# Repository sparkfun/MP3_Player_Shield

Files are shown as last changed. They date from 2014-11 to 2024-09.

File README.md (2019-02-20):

SparkFun MP3 Player Shield
==========================

SparkFun MP3 Player Shield  

[*SparkFun MP3 Player Shield (DEV-2660)*](https://www.sparkfun.com/products/12660)

The MP3 Player Shield has a microSD socket, VS1053 decoder IC and all the supporting circuitry to be able to decode and play MP3s from an Arduino.

Repository Contents
-------------------

* **/Documentation** - Data sheets, additional product information
* **/Firmware** - Multiple examples of how to read MP3 files and send them to the VS1053.
* **/Hardware** - All Eagle design files (.brd, .sch)
* **/Production** - Production panel files (.brd)

Documentation
--------------
* **[Hookup Guide](https://learn.sparkfun.com/tutorials/mp3-player-shield-hookup-guide-v15)** - Basic hookup guide for the Mp3 Shield.
* **[SparkFun Fritzing repo](https://github.com/sparkfun/Fritzing_Parts)** - Fritzing diagrams for SparkFun products.
* **[SparkFun 3D Model repo](https://github.com/sparkfun/3D_Models)** - 3D models of SparkFun products. 

Product Versions
----------------
* [DEV-09736](https://www.sparkfun.com/products/retired/9736)- Version 1.0. Retired. 
* [DEV-10628](https://www.sparkfun.com/products/retired/10628)- Version 1.3. Retired. 
* [DEV-12660](https://www.sparkfun.com/products/12660) - Version 1.5. Current. 

Version History
---------------
* [v1.3](https://github.com/sparkfun/MP3_Player_Shield/tree/V_1.3) - Version 1.3 GitHub files. Retired. 
* [v1.5](https://github.com/sparkfun/MP3_Player_Shield/tree/V_1.5) - Version 1.5 GitHub files. Current. 

License Information
-------------------

This product is _**open source**_! 

Please review the LICENSE.md file for license information. 

If you have any questions or concerns on licensing, please contact techsupport@sparkfun.com.

Distributed as-is; no warranty is given.

- Your friends at SparkFun.

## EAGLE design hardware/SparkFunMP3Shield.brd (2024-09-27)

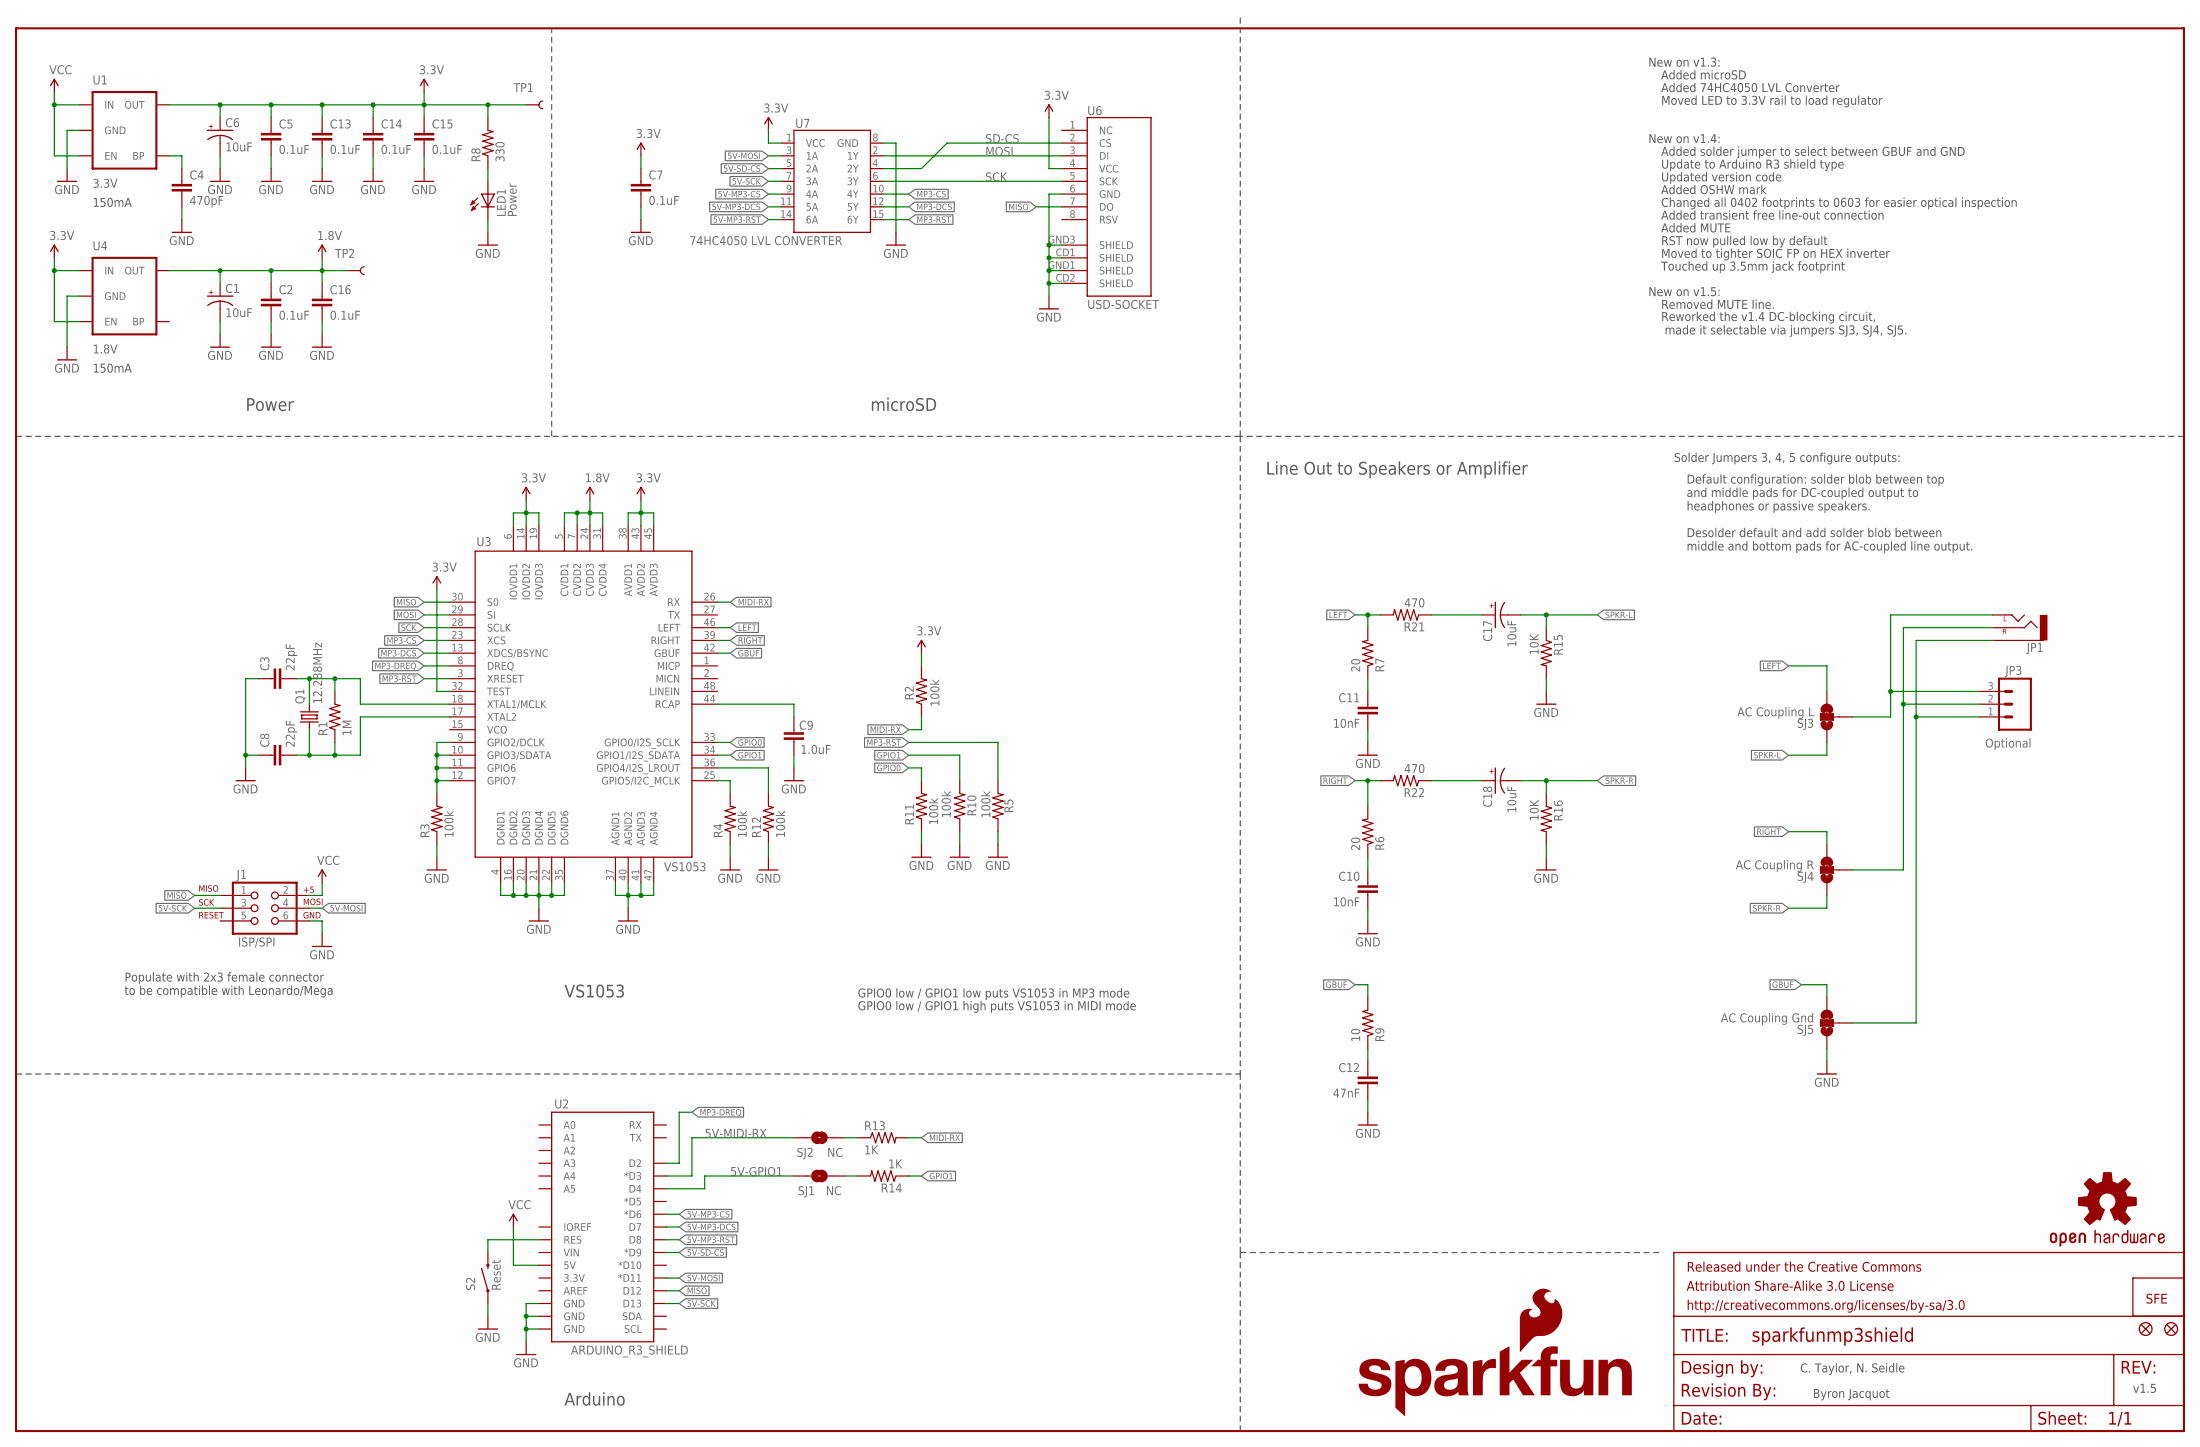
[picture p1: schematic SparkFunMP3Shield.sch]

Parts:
C1, C6, C17, C18: 10uF; EIA3216
C2, C5, C7, C13, C14, C15, C16: 0.1uF; 0603-CAP
C3, C8: 22pF; 0603-CAP
C4: 470pF; 0603-CAP
C9: 1.0uF; 0603-CAP
C10, C11: 10nF; 0603-CAP
C12: 47nF; 0603-CAP
FRAME1: FRAME-LEDGER; CREATIVE_COMMONS
J1: ISP/SPI; 2X3
JP1: AUDIO-JACKSMD2; AUDIO-JACK-3.5MM-SMD
JP3: Optional; 1X03
LED1: Power; LED-0603
LOGO1: OSHW-LOGOS; OSHW-LOGO-S
LOGO2: SFE_LOGO_NAME_FLAME.1_INCH; SFE_LOGO_NAME_FLAME_.1
Q1: 12.288MHz; CRYSTAL-SMD-5X3
R1: 1M; 0603-RES
R2, R3, R4, R5, R10, R11, R12: 100k; 0603-RES
R6, R7: 20; 0603-RES
R8: 330; 0603-RES
R9: 10; 0603-RES
R13, R14: 1K; 0603-RES
R15, R16: 10K; 0603-RES
R21, R22: 470; 0603-RES
S2: Reset; TACTILE_SWITCH_SMD
SJ1, SJ2: NC; SJ_2S-TRACE
SJ3: AC Coupling L; SMT-JUMPER_3_1-NC_TRACE_SILK
SJ4: AC Coupling R; SMT-JUMPER_3_1-NC_TRACE_SILK
SJ5: AC Coupling Gnd; SMT-JUMPER_3_1-NC_TRACE_SILK
TP1, TP2: TEST-POINT3X5; PAD.03X.05
U1: 3.3V; SOT23-5
U2: ARDUINO_R3_SHIELD; UNO_R3_SHIELD
U3: VS1053; LQFP-48
U4: 1.8V; SC70
U6: USD-SOCKET; MICRO-SD-SOCKET-PP
U7: 74HC4050 LVL CONVERTER; SO016
U$1: REVISION
U$4, U$5: FIDUCIAL1X2; FIDUCIAL-1X2
U$8: LOGO-SFENEW; SFE-NEW-WEBLOGO

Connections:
1.8V: C1.A (+), C2.1, C16.1, TP2.P$1, U3.5 (CVDD1), U3.7 (CVDD2), U3.24 (CVDD3), U3.31 (CVDD4), U4.5 (OUT)
3.3V: C5.1, C6.A (+), C7.1, C13.1, C14.1, C15.1, R2.2, R8.2, TP1.P$1, U1.5 (OUT), U3.6 (IOVDD1), U3.14 (IOVDD2), U3.19 (IOVDD3), U3.32 (TEST), U3.38 (AVDD1), U3.43 (AVDD2), U3.45 (AVDD3), U4.1 (IN), U4.3 (EN), U6.4 (VCC), U7.1 (VCC)
5V-GPIO1: SJ1.2, U2.D4
5V-MIDI-RX: SJ2.1, U2.D3 (*D3)
5V-MOSI: J1.4, U2.D11 (*D11), U7.3 (1A)
5V-MP3-CS: U2.D6 (*D6), U7.9 (4A)
5V-MP3-DCS: U2.D7, U7.11 (5A)
5V-MP3-RST: U2.D8, U7.14 (6A)
5V-SCK: J1.3, U2.D13, U7.7 (3A)
5V-SD-CS: U2.D9 (*D9), U7.5 (2A)
ARST: S2.3 (2), U2.RES
G1: R3.2, U3.9 (GPIO2/DCLK), U3.10 (GPIO3/SDATA), U3.11 (GPIO6), U3.12 (GPIO7)
G2: R4.2, U3.25 (GPIO5/I2C_MCLK)
GBUF: R9.2, SJ5.3, U3.42 (GBUF)
GND: C1.C (-), C2.2, C3.1, C4.2, C5.2, C6.C (-), C7.2, C8.1, C9.1, C10.2, C11.2, C12.2, C13.2, C14.2, C15.2, C16.2, J1.6, LED1.C, R3.1, R4.1, R5.1, R10.1, R11.1, R12.1, R15.2, R16.2, S2.1, SJ5.1, U1.2 (GND), U2.GND@0 (GND), U2.GND@1 (GND), U2.GND@2 (GND), U3.4 (DGND1), U3.16 (DGND2), U3.20 (DGND3), U3.21 (DGND4), U3.22 (DGND5), U3.35 (DGND6), U3.37 (AGND1), U3.40 (AGND2), U3.41 (AGND3), U3.47 (AGND4), U4.2 (GND), U6.6 (GND), U6.CD1 (SHIELD), U6.CD2 (SHIELD), U6.GND1 (SHIELD), U6.GND3 (SHIELD), U7.8 (GND)
GPIO0: R11.2, U3.33 (GPIO0/I2S_SCLK)
GPIO1: R10.2, R14.1, U3.34 (GPIO1/I2S_SDATA)
GPIO4: R12.2, U3.36 (GPIO4/I2S_LROUT)
LEFT: R7.2, R21.2, SJ3.3, U3.46 (LEFT)
MIDI-RX: R2.1, R13.2, U3.26 (RX)
MISO: J1.1, U2.D12, U3.30 (S0), U6.7 (DO)
MOSI: U3.29 (SI), U6.3 (DI), U7.2 (1Y)
MP3-CS: U3.23 (XCS), U7.10 (4Y)
MP3-DCS: U3.13 (XDCS/BSYNC), U7.12 (5Y)
MP3-DREQ: U2.D2, U3.8 (DREQ)
MP3-RST: R5.2, U3.3 (XRESET), U7.15 (6Y)
unnamed: C12.1, R9.1
unnamed: C10.1, R6.1
unnamed: R14.2, SJ1.1
unnamed: C11.1, R7.1
unnamed: LED1.A, R8.1
unnamed: R13.1, SJ2.2
unnamed: C3.2, Q1.3 (2), R1.2, U3.18 (XTAL1/MCLK)
unnamed: C8.2, Q1.1, R1.1, U3.17 (XTAL2)
unnamed: JP1.SLEEVE, JP3.1, SJ5.2
unnamed: JP1.RING (RIGHT), JP3.2, SJ4.2
unnamed: JP1.TIP (LEFT), JP3.3, SJ3.2
unnamed: C18.A (+), R22.1
unnamed: C17.A (+), R21.1
unnamed: C4.1, U1.4 (BP)
RCAP: C9.2, U3.44 (RCAP)
RIGHT: R6.2, R22.2, SJ4.3, U3.39 (RIGHT)
SCK: U3.28 (SCLK), U6.5 (SCK), U7.6 (3Y)
SD-CS: U6.2 (CS), U7.4 (2Y)
SPKR-L: C17.C (-), R15.1, SJ3.1
SPKR-R: C18.C (-), R16.1, SJ4.1
VCC: J1.2, U1.1 (IN), U1.3 (EN), U2.5V

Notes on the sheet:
GPIO0 low / GPIO1 high puts VS1053 in MIDI mode
C. Taylor, N. Seidle
New on v1.3:
GPIO0 low / GPIO1 low puts VS1053 in MP3 mode
microSD
Power
Line Out to Speakers or Amplifier
Arduino
VS1053
Moved LED to 3.3V rail to load regulator
Added microSD
Added 74HC4050 LVL Converter
New on v1.4:
Added solder jumper to select between GBUF and GND
Default configuration: solder blob between top and middle pads for DC-coupled output to headphones or passive speakers. Desolder default and add solder blob between middle and bottom pads for AC-coupled line output.
Update to Arduino R3 shield type
Updated version code
Added OSHW mark
Changed all 0402 footprints to 0603 for easier optical inspection
Added transient free line-out connection
Added MUTE
Solder Jumpers 3, 4, 5 configure outputs:
150mA
v1.5
RST now pulled low by default
Populate with 2x3 female connector to be compatible with Leonardo/Mega
Moved to tighter SOIC FP on HEX inverter
Touched up 3.5mm jack footprint
Byron Jacquot
New on v1.5:
Removed MUTE line.
Reworked the v1.4 DC-blocking circuit, made it selectable via jumpers SJ3, SJ4, SJ5.

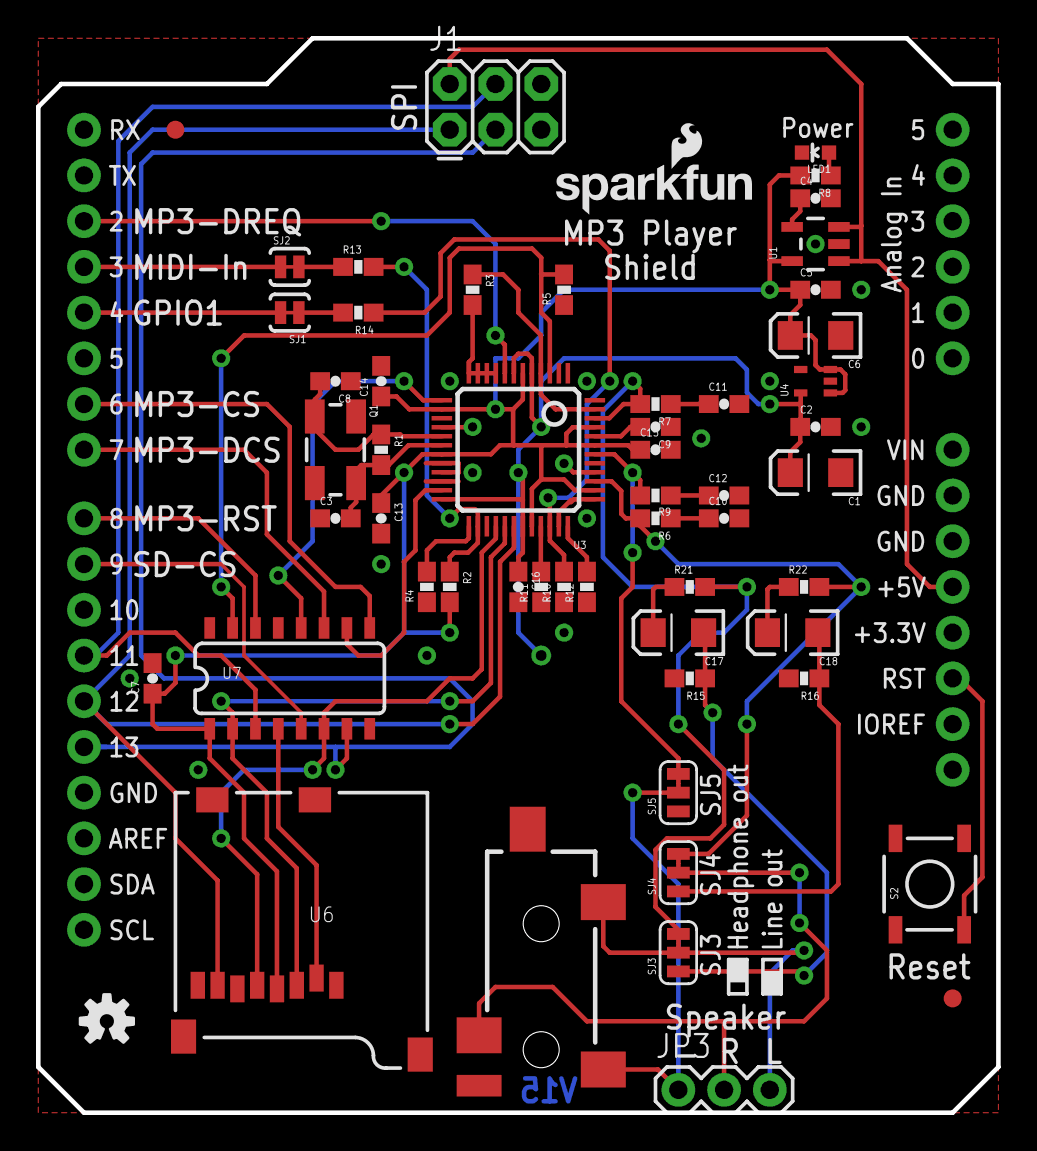
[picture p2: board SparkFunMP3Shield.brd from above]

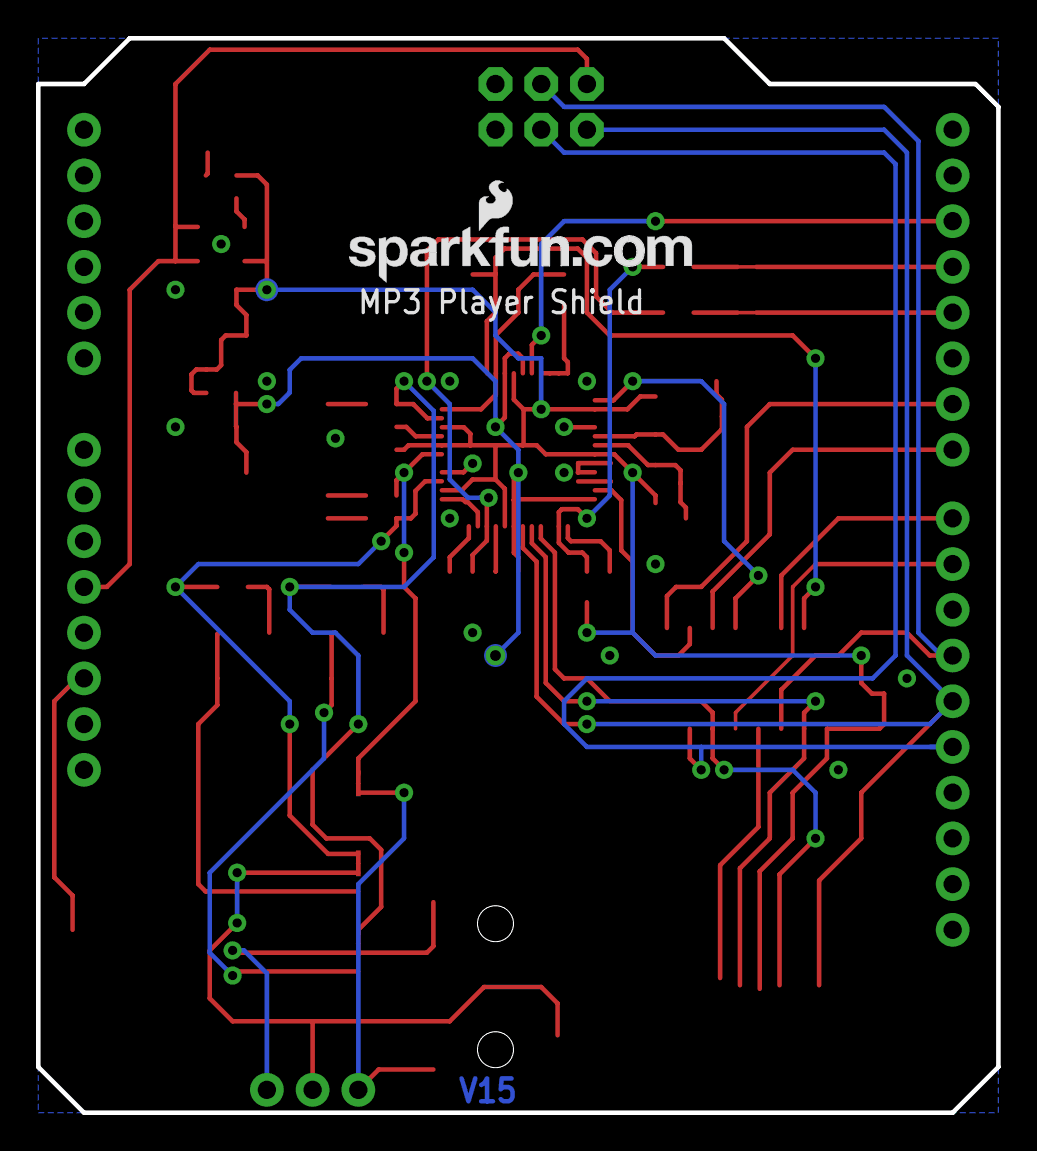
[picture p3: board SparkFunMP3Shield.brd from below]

Board: 2 copper layers, 53.3 x 59.7 mm, 62 parts (3 on the bottom side), 47 nets.

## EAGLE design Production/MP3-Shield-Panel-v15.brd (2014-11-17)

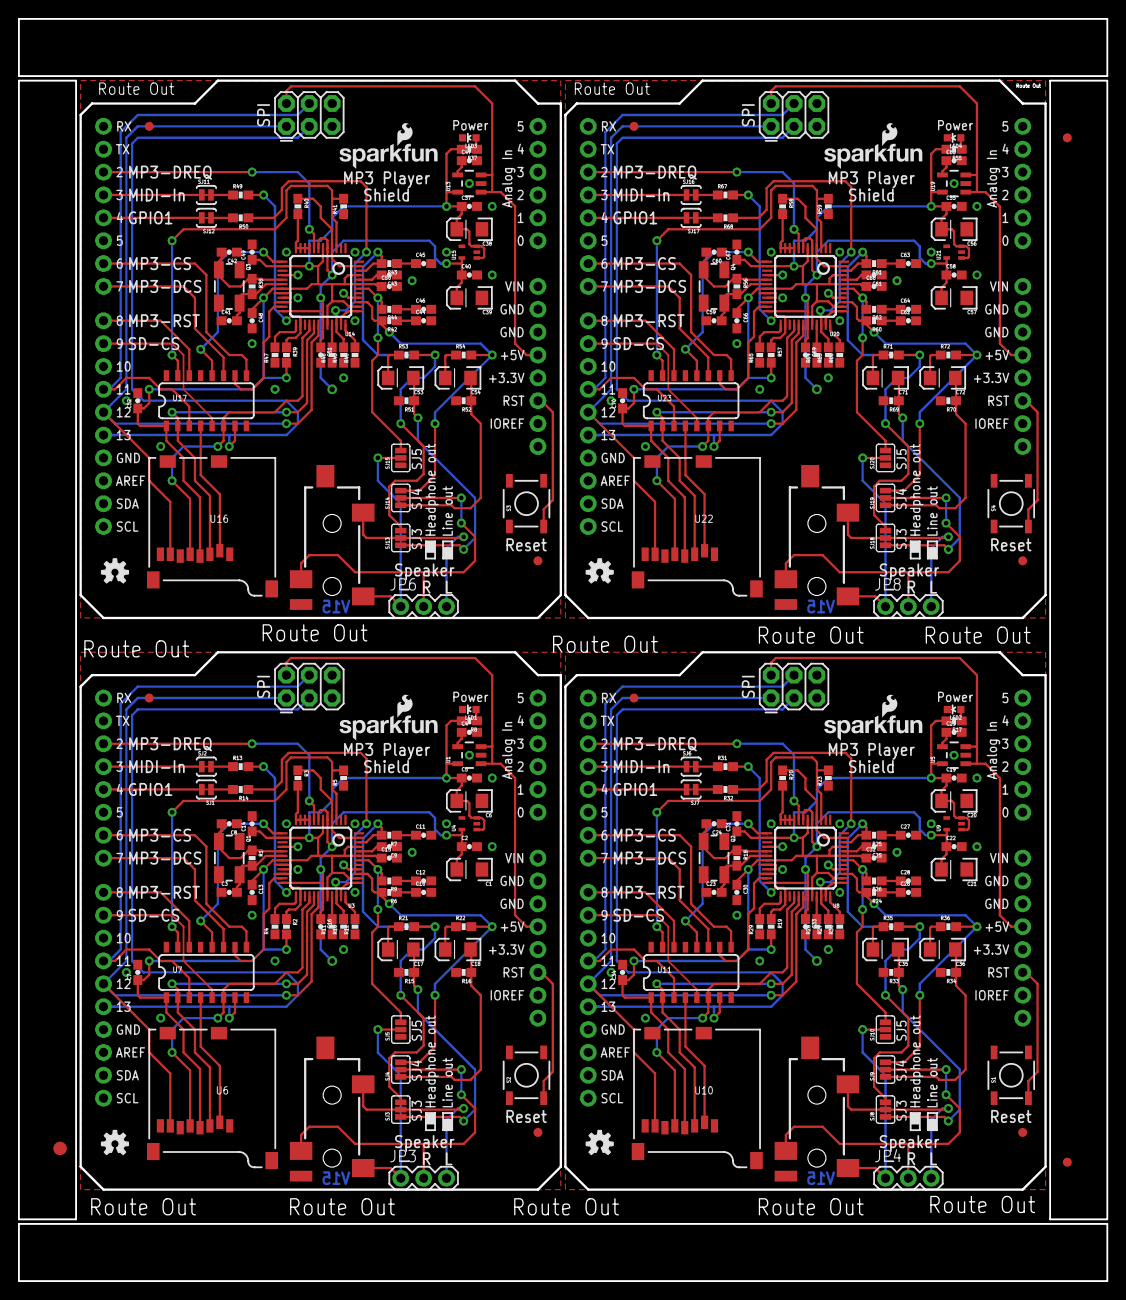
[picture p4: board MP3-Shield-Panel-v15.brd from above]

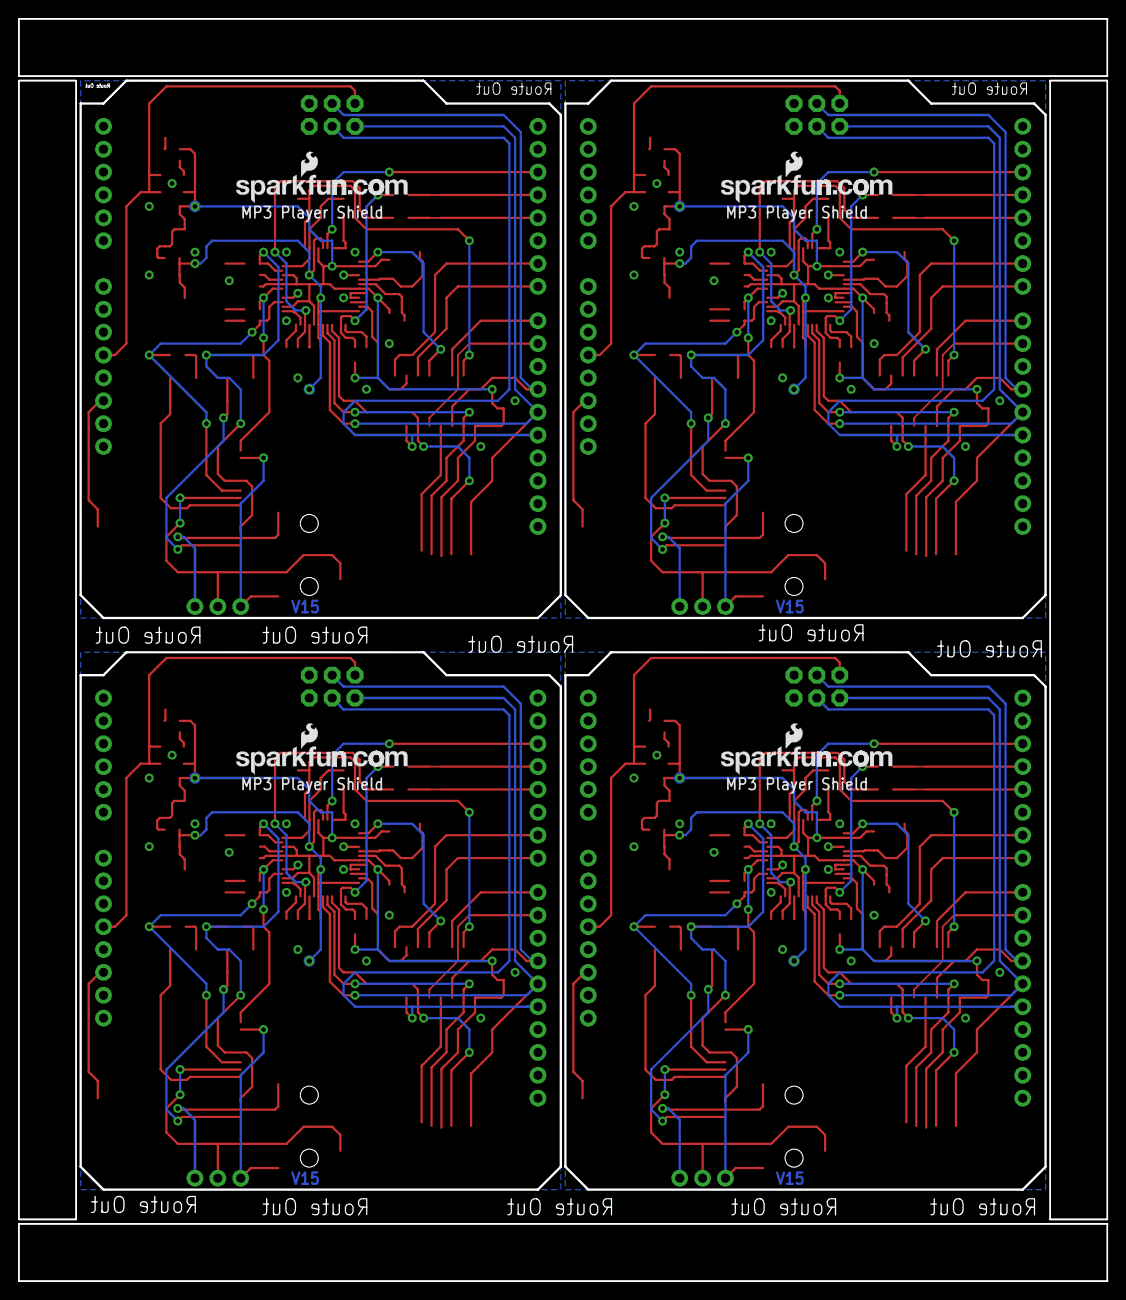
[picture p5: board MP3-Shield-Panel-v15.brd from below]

Board: 2 copper layers, 120.9 x 140.2 mm, 243 parts (12 on the bottom side), 188 nets.

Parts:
C1, C6, C17, C18, C20, C21, C35, C36, C38, C39, C53, C54, C56, C57, C71, C72: 10uF; EIA3216
C2, C5, C7, C13, C14, C15, C16, C19, C22, C30, C31, C32, C33, C34, C37, C40, C48, C49, C50, C51, C52, C55, C58, C66, C67, C68, C69, C70: 0.1uF; 0603-CAP
C3, C8, C23, C24, C41, C42, C59, C60: 22pF; 0603-CAP
C4, C29, C47, C65: 470pF; 0603-CAP
C9, C25, C43, C61: 1.0uF; 0603-CAP
C10, C11, C26, C27, C44, C45, C62, C63: 10nF; 0603-CAP
C12, C28, C46, C64: 47nF; 0603-CAP
E$1: FIDUCIAL-1.5X3
E$4, E$5: FIDUCIAL-1X2
J1, J2, J3, J4: ISP/SPI; 2X3
JP1, JP2, JP5, JP7: AUDIO-JACK-3.5MM-SMD
JP3, JP4, JP6, JP8: Optional; 1X03
LED1, LED2, LED3, LED4: Power; LED-0603
LOGO1, LOGO3, LOGO5, LOGO7: OSHW-LOGOS; OSHW-LOGO-S
LOGO2, LOGO4, LOGO6, LOGO8: SFE_LOGO_NAME_FLAME.1_INCH; SFE_LOGO_NAME_FLAME_.1
Q1, Q2, Q3, Q4: 12.288MHz; CRYSTAL-SMD-5X3
R1, R18, R38, R56: 1M; 0603-RES
R2, R3, R4, R5, R10, R11, R12, R19, R20, R23, R27, R28, R29, R30, R39, R40, R41, R45, R46, R47, R48, R57, R58, R59, R63, R64, R65, R66: 100k; 0603-RES
R6, R7, R24, R25, R42, R43, R60, R61: 20; 0603-RES
R8, R17, R37, R55: 330; 0603-RES
R9, R26, R44, R62: 10; 0603-RES
R13, R14, R31, R32, R49, R50, R67, R68: 1K; 0603-RES
R15, R16, R33, R34, R51, R52, R69, R70: 10K; 0603-RES
R21, R22, R35, R36, R53, R54, R71, R72: 470; 0603-RES
S1, S2, S3, S4: Reset; TACTILE_SWITCH_SMD
SJ1, SJ2, SJ6, SJ7, SJ11, SJ12, SJ16, SJ17: NC; SJ_2S-TRACE
SJ3, SJ8, SJ13, SJ18: AC Coupling L; PAD-JUMPER-3-2OF3_NC_BY_PASTE_YES_SILK_FULL_BOX
SJ4, SJ9, SJ14, SJ19: AC Coupling R; PAD-JUMPER-3-2OF3_NC_BY_PASTE_YES_SILK_FULL_BOX
SJ5, SJ10, SJ15, SJ20: AC Coupling Gnd; PAD-JUMPER-3-2OF3_NC_BY_PASTE_YES_SILK_FULL_BOX
TP1, TP2, TP3, TP4, TP5, TP6, TP7, TP8: PAD.03X.05
U1, U5, U13, U19: 3.3V; SOT23-5
U2, U12, U18, U24: ARDUINO_R3_SHIELD; UNO_R3_SHIELD
U3, U8, U14, U20: VS1053; LQFP-48
U4, U9, U15, U21: 1.8V; SC70
U6, U10, U16, U22: USD-SOCKET; MICRO-SD-SOCKET-PP
U7, U11, U17, U23: 74HC4050 LVL CONVERTER; SO016
U$1, U$2, U$4, U$5, U$6, U$7, U$10, U$11: FIDUCIAL1X2; FIDUCIAL-1X2
U$3, U$8, U$9, U$12: LOGO-SFENEW; SFE-NEW-WEBLOGO

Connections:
1.8V: C1.A, C2.1, C16.1, TP2.P$1, U3.5, U3.7, U3.24, U3.31, U4.5
1.8V1: C21.A, C22.1, C33.1, TP4.P$1, U8.5, U8.7, U8.24, U8.31, U9.5
1.8V2: C39.A, C40.1, C51.1, TP6.P$1, U14.5, U14.7, U14.24, U14.31, U15.5
1.8V3: C57.A, C58.1, C69.1, TP8.P$1, U20.5, U20.7, U20.24, U20.31, U21.5
3.3V: C5.1, C6.A, C7.1, C13.1, C14.1, C15.1, R2.2, R8.2, TP1.P$1, U1.5, U3.6, U3.14, U3.19, U3.32, U3.38, U3.43, U3.45, U4.1, U4.3, U6.4, U7.1
3.3V1: C19.1, C20.A, C30.1, C31.1, C32.1, C34.1, R17.2, R19.2, TP3.P$1, U5.5, U8.6, U8.14, U8.19, U8.32, U8.38, U8.43, U8.45, U9.1, U9.3, U10.4, U11.1
3.3V2: C37.1, C38.A, C48.1, C49.1, C50.1, C52.1, R37.2, R39.2, TP5.P$1, U13.5, U14.6, U14.14, U14.19, U14.32, U14.38, U14.43, U14.45, U15.1, U15.3, U16.4, U17.1
3.3V3: C55.1, C56.A, C66.1, C67.1, C68.1, C70.1, R55.2, R57.2, TP7.P$1, U19.5, U20.6, U20.14, U20.19, U20.32, U20.38, U20.43, U20.45, U21.1, U21.3, U22.4, U23.1
5V-GPIO1: SJ1.2, U2.D4
5V-GPIO2: SJ7.2, U12.D4
5V-GPIO3: SJ12.2, U18.D4
5V-GPIO4: SJ17.2, U24.D4
5V-MIDI-RX: SJ2.1, U2.D3
5V-MIDI-RX1: SJ6.1, U12.D3
5V-MIDI-RX2: SJ11.1, U18.D3
5V-MIDI-RX3: SJ16.1, U24.D3
5V-MOSI: J1.4, U2.D11, U7.3
5V-MOSI1: J2.4, U11.3, U12.D11
5V-MOSI2: J3.4, U17.3, U18.D11
5V-MOSI3: J4.4, U23.3, U24.D11
5V-MP3-CS: U2.D6, U7.9
5V-MP3-CS1: U11.9, U12.D6
5V-MP3-CS2: U17.9, U18.D6
5V-MP3-CS3: U23.9, U24.D6
5V-MP3-DCS: U2.D7, U7.11
5V-MP3-DCS1: U11.11, U12.D7
5V-MP3-DCS2: U17.11, U18.D7
5V-MP3-DCS3: U23.11, U24.D7
5V-MP3-RST: U2.D8, U7.14
5V-MP3-RST1: U11.14, U12.D8
5V-MP3-RST2: U17.14, U18.D8
5V-MP3-RST3: U23.14, U24.D8
5V-SCK: J1.3, U2.D13, U7.7
5V-SCK1: J2.3, U11.7, U12.D13
5V-SCK2: J3.3, U17.7, U18.D13
5V-SCK3: J4.3, U23.7, U24.D13
5V-SD-CS: U2.D9, U7.5
5V-SD-CS1: U11.5, U12.D9
5V-SD-CS2: U17.5, U18.D9
5V-SD-CS3: U23.5, U24.D9
ARST: S2.3, U2.RES
ARST1: S1.3, U12.RES
ARST2: S3.3, U18.RES
ARST3: S4.3, U24.RES
G1: R3.2, U3.9, U3.10, U3.11, U3.12
G2: R4.2, U3.25
G3: R20.2, U8.9, U8.10, U8.11, U8.12
G4: R29.2, U8.25
G5: R40.2, U14.9, U14.10, U14.11, U14.12
G6: R47.2, U14.25
G7: R58.2, U20.9, U20.10, U20.11, U20.12
G8: R65.2, U20.25
GBUF: R9.2, SJ5.3, U3.42
GBUF1: R26.2, SJ10.3, U8.42
GBUF2: R44.2, SJ15.3, U14.42
GBUF3: R62.2, SJ20.3, U20.42
GND: C1.C, C2.2, C3.1, C4.2, C5.2, C6.C, C7.2, C8.1, C9.1, C10.2, C11.2, C12.2, C13.2, C14.2, C15.2, C16.2, J1.6, LED1.C, R3.1, R4.1, R5.1, R10.1, R11.1, R12.1, R15.2, R16.2, S2.1, SJ5.1, U1.2, U2.GND@0, U2.GND@1, U2.GND@2, U3.4, U3.16, U3.20, U3.21, U3.22, U3.35, U3.37, U3.40, U3.41, U3.47, U4.2, U6.6, U6.CD1, U6.CD2, U6.GND1, U6.GND3, U7.8
GND1: C19.2, C20.C, C21.C, C22.2, C23.1, C24.1, C25.1, C26.2, C27.2, C28.2, C29.2, C30.2, C31.2, C32.2, C33.2, C34.2, J2.6, LED2.C, R20.1, R23.1, R27.1, R28.1, R29.1, R30.1, R33.2, R34.2, S1.1, SJ10.1, U5.2, U8.4, U8.16, U8.20, U8.21, U8.22, U8.35, U8.37, U8.40, U8.41, U8.47, U9.2, U10.6, U10.CD1, U10.CD2, U10.GND1, U10.GND3, U11.8, U12.GND@0, U12.GND@1, U12.GND@2
GND2: C37.2, C38.C, C39.C, C40.2, C41.1, C42.1, C43.1, C44.2, C45.2, C46.2, C47.2, C48.2, C49.2, C50.2, C51.2, C52.2, J3.6, LED3.C, R40.1, R41.1, R45.1, R46.1, R47.1, R48.1, R51.2, R52.2, S3.1, SJ15.1, U13.2, U14.4, U14.16, U14.20, U14.21, U14.22, U14.35, U14.37, U14.40, U14.41, U14.47, U15.2, U16.6, U16.CD1, U16.CD2, U16.GND1, U16.GND3, U17.8, U18.GND@0, U18.GND@1, U18.GND@2
GND3: C55.2, C56.C, C57.C, C58.2, C59.1, C60.1, C61.1, C62.2, C63.2, C64.2, C65.2, C66.2, C67.2, C68.2, C69.2, C70.2, J4.6, LED4.C, R58.1, R59.1, R63.1, R64.1, R65.1, R66.1, R69.2, R70.2, S4.1, SJ20.1, U19.2, U20.4, U20.16, U20.20, U20.21, U20.22, U20.35, U20.37, U20.40, U20.41, U20.47, U21.2, U22.6, U22.CD1, U22.CD2, U22.GND1, U22.GND3, U23.8, U24.GND@0, U24.GND@1, U24.GND@2
GPIO0: R11.2, U3.33
GPIO1: R10.2, R14.1, U3.34
GPIO2: R28.2, U8.33
GPIO3: R27.2, R32.1, U8.34
GPIO4: R12.2, U3.36
GPIO5: R30.2, U8.36
GPIO6: R46.2, U14.33
GPIO7: R45.2, R50.1, U14.34
GPIO8: R48.2, U14.36
GPIO9: R64.2, U20.33
GPIO10: R63.2, R68.1, U20.34
GPIO11: R66.2, U20.36
LEFT: R7.2, R21.2, SJ3.3, U3.46
LEFT1: R25.2, R35.2, SJ8.3, U8.46
LEFT2: R43.2, R53.2, SJ13.3, U14.46
LEFT3: R61.2, R71.2, SJ18.3, U20.46
MIDI-RX: R2.1, R13.2, U3.26
MIDI-RX1: R19.1, R31.2, U8.26
MIDI-RX2: R39.1, R49.2, U14.26
MIDI-RX3: R57.1, R67.2, U20.26
MISO: J1.1, U2.D12, U3.30, U6.7
MISO1: J2.1, U8.30, U10.7, U12.D12
MISO2: J3.1, U14.30, U16.7, U18.D12
MISO3: J4.1, U20.30, U22.7, U24.D12
MOSI: U3.29, U6.3, U7.2
MOSI1: U8.29, U10.3, U11.2
MOSI2: U14.29, U16.3, U17.2
MOSI3: U20.29, U22.3, U23.2
MP3-CS: U3.23, U7.10
MP3-CS1: U8.23, U11.10
MP3-CS2: U14.23, U17.10
MP3-CS3: U20.23, U23.10
MP3-DCS: U3.13, U7.12
MP3-DCS1: U8.13, U11.12
MP3-DCS2: U14.13, U17.12
MP3-DCS3: U20.13, U23.12
MP3-DREQ: U2.D2, U3.8
MP3-DREQ1: U8.8, U12.D2
MP3-DREQ2: U14.8, U18.D2
MP3-DREQ3: U20.8, U24.D2
MP3-RST: R5.2, U3.3, U7.15
MP3-RST1: R23.2, U8.3, U11.15
MP3-RST2: R41.2, U14.3, U17.15
MP3-RST3: R59.2, U20.3, U23.15
unnamed: LED2.A, R17.1
unnamed: C12.1, R9.1
unnamed: C10.1, R6.1
unnamed: R14.2, SJ1.1
unnamed: C11.1, R7.1
unnamed: LED1.A, R8.1
unnamed: C23.2, Q2.3, R18.2, U8.18
unnamed: R13.1, SJ2.2
unnamed: C3.2, Q1.3, R1.2, U3.18
unnamed: C8.2, Q1.1, R1.1, U3.17
unnamed: C24.2, Q2.1, R18.1, U8.17
unnamed: JP1.SLEEVE, JP3.1, SJ5.2
unnamed: JP1.RING, JP3.2, SJ4.2
unnamed: JP1.TIP, JP3.3, SJ3.2
unnamed: C28.1, R26.1
unnamed: C27.1, R25.1
unnamed: C18.A, R22.1
unnamed: C26.1, R24.1
unnamed: C17.A, R21.1
unnamed: C29.1, U5.4
unnamed: R31.1, SJ6.2
unnamed: R32.2, SJ7.1
unnamed: C36.A, R36.1
unnamed: C35.A, R35.1
unnamed: JP2.SLEEVE, JP4.1, SJ10.2
unnamed: JP2.RING, JP4.2, SJ9.2
unnamed: JP2.TIP, JP4.3, SJ8.2
unnamed: LED3.A, R37.1
unnamed: C41.2, Q3.3, R38.2, U14.18
unnamed: C42.2, Q3.1, R38.1, U14.17
unnamed: C46.1, R44.1
unnamed: C45.1, R43.1
unnamed: C44.1, R42.1
unnamed: C47.1, U13.4
unnamed: R49.1, SJ11.2
unnamed: R50.2, SJ12.1
unnamed: C54.A, R54.1
unnamed: C53.A, R53.1
unnamed: JP5.SLEEVE, JP6.1, SJ15.2
unnamed: JP5.RING, JP6.2, SJ14.2
unnamed: JP5.TIP, JP6.3, SJ13.2
unnamed: LED4.A, R55.1
unnamed: C59.2, Q4.3, R56.2, U20.18
unnamed: C60.2, Q4.1, R56.1, U20.17
unnamed: C64.1, R62.1
unnamed: C63.1, R61.1
unnamed: C62.1, R60.1
unnamed: C65.1, U19.4
unnamed: R67.1, SJ16.2
unnamed: R68.2, SJ17.1
unnamed: C72.A, R72.1
unnamed: C71.A, R71.1
unnamed: JP7.SLEEVE, JP8.1, SJ20.2
unnamed: JP7.RING, JP8.2, SJ19.2
unnamed: JP7.TIP, JP8.3, SJ18.2
unnamed: C4.1, U1.4
RCAP: C9.2, U3.44
RCAP1: C25.2, U8.44
RCAP2: C43.2, U14.44
RCAP3: C61.2, U20.44
RIGHT: R6.2, R22.2, SJ4.3, U3.39
RIGHT1: R24.2, R36.2, SJ9.3, U8.39
RIGHT2: R42.2, R54.2, SJ14.3, U14.39
RIGHT3: R60.2, R72.2, SJ19.3, U20.39
SCK: U3.28, U6.5, U7.6
SCK1: U8.28, U10.5, U11.6
SCK2: U14.28, U16.5, U17.6
SCK3: U20.28, U22.5, U23.6
SD-CS: U6.2, U7.4
SD-CS1: U10.2, U11.4
SD-CS2: U16.2, U17.4
SD-CS3: U22.2, U23.4
SPKR-L: C17.C, R15.1, SJ3.1
SPKR-L1: C35.C, R33.1, SJ8.1
SPKR-L2: C53.C, R51.1, SJ13.1
SPKR-L3: C71.C, R69.1, SJ18.1
SPKR-R: C18.C, R16.1, SJ4.1
SPKR-R1: C36.C, R34.1, SJ9.1
SPKR-R2: C54.C, R52.1, SJ14.1
SPKR-R3: C72.C, R70.1, SJ19.1
VCC: J1.2, U1.1, U1.3, U2.5V
VCC1: J2.2, U5.1, U5.3, U12.5V
VCC2: J3.2, U13.1, U13.3, U18.5V
VCC3: J4.2, U19.1, U19.3, U24.5V

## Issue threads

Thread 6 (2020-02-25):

SfFatUtil.h doesn't exist anymore

Patronics, 2020-02-25:
When I'm trying to compile the code provided in the firmware directory, I get the error that it can't find "SdFatUtil.h", which according to [this discussion](https://forum.arduino.cc/index.php?topic=514087.0) is no longer used in modern versions of SdFat.

MaurinElectroTextile, 2021-12-07:
Is this an update ? https://github.com/troisiemetype/SFEMP3Shield

nseidle, 2021-12-15:
Examples have been updated. Far more simple now.

Closed 2021-12-15.

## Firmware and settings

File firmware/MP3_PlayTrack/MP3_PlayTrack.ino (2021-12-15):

/*
  4-28-2011
  Spark Fun Electronics 2011
  Nathan Seidle

  This code is public domain but you buy me a beer if you use this and we meet someday (Beerware license).

  This example code works with the MP3 Shield (https://www.sparkfun.com/products/12660) and plays a MP3 from the
  SD card called 'track001.mp3'. The theory is that you can load a microSD card up with a bunch of MP3s and
  then play a given 'track' depending on some sort of input such as which pin is pulled low.

  Attach the shield to an Arduino. Load code (after editing Sd2PinMap.h) then open the terminal at 57600bps. This
  example shows that it takes ~30ms to load up the VS1053 buffer. We can then do whatever we want for ~100ms
  before we need to return to filling the buffer (for another 30ms).

  This code is heavily based on the example code I wrote to control the MP3 shield found here:
  http://www.sparkfun.com/products/9736
  This example code extends the previous example by reading the MP3 from an SD card and file rather than from internal
  memory of the ATmega. Because the current MP3 shield does not have a microSD socket, you will need to add the microSD
  shield to your Arduino stack.

  The main gotcha from all of this is that you have to make sure your CS pins for each device on an SPI bus is carefully
  declared. For the CS on the SD card, you need to correctly set it with pin_microSD_CS. 

  Four pins are needed to control the VS1503:
  DREQ
  CS
  DCS
  Reset (optional but good to have access to)
  Plus the SPI bus

  Only the SPI bus pins and another CS pin are needed to control the microSD card.

  What surprised me is the fact that with a normal MP3 we can do other things for up to 100ms while the MP3 IC crunches
  through its fairly large buffer of 2048 bytes. As long as you keep your sensor checks or serial reporting to under
  100ms and leave ~30ms to then replenish the MP3 buffer, you can do quite a lot while the MP3 is playing glitch free.
*/

//microSD Interface
//-=-=-=-=-=-=-=-=-=-=-=-=-=-=-=-=-=-=-=-=-=-=-=-=-=-=-=-=-=-=-=-=-
#include <SPI.h>
#include "SdFat.h" //http://librarymanager/All#SdFat_exFat by Bill Greiman. We currently use v2.1.2

const int pin_microSD_CS = 9; //Default pin for the SparkFun MP3 Shield
SdFat sd;
//-=-=-=-=-=-=-=-=-=-=-=-=-=-=-=-=-=-=-=-=-=-=-=-=-=-=-=-=-=-=-=-=-

//MP3 Shield Interface
//-=-=-=-=-=-=-=-=-=-=-=-=-=-=-=-=-=-=-=-=-=-=-=-=-=-=-=-=-=-=-=-=-
#include "vs1053_SdFat.h" //http://librarymanager/All#vs1053_sdFat by mpflaga

vs1053 MP3player; 
//-=-=-=-=-=-=-=-=-=-=-=-=-=-=-=-=-=-=-=-=-=-=-=-=-=-=-=-=-=-=-=-=-

void setup()
{
  Serial.begin(115200); //Use serial for debugging
  Serial.println("MP3 Testing");

  if (sd.begin(pin_microSD_CS) == false)
  {
    Serial.println(F("SD init failed. Is card present? Formatted? Freezing..."));
    while (1);
  }

  MP3player.begin();
  MP3player.setVolume(40, 40); //(Left, Right) 40 is pretty good for ear buds

  //Let's play a track of a given number
  //This is the name of the file on the microSD card you would like to play
  //Stick with normal 8.3 nomeclature. All lower-case works well.
  //Note: you must name the tracks on the SD card with 001, 002, 003, etc.
  //For example, the code is expecting to play 'track002.mp3', not track2.mp3.
  
  char trackName[] = "track001.mp3";
  int trackNumber = 1;

  sprintf(trackName, "track%03d.mp3", trackNumber); //Splice the new file number into this file name

  MP3player.playMP3(trackName);
}

void loop()
{
  Serial.println("All done!");
  delay(1000);
}

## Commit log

2013-11-27 Initial commit at v1.3
    Repo was started at PCB date code 4-1-11.
    [MP3 Shield-v13.brd, MP3 Shield-v13.sch]
2014-09-26 Initial commit of V1.5
    1.5 replaces 1.4.
    Very much WIP with this checkin.
    [MP3 Shield-v13.brd, MP3 Shield-v13.sch, MP3 Shield.brd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]
2014-09-26 More WIP.
    [MP3 Shield.brd, MP3 Shield.sch]
2014-09-26 Yet more WIP
    [MP3 Shield.brd, MP3 Shield.sch]
2014-10-13 V1.5 ready for protos.
    Board routed and ready for protos.
    [MP3 Shield.brd, MP3 Shield.sch]
2014-11-05 Ready to review for reds
    Reorganized the solder jumpers for output coupling selection.
    [MP3 Shield.brd, MP3 Shield.sch]
2014-11-10 Tweaking after review
    Clarifying solder jumpers for output configuration.
    [MP3 Shield.brd, MP3 Shield.sch]
2014-11-12 Updating based on QC checklist.
    [MP3 Shield.brd, MP3 Shield.sch]
2014-11-17 created panel v15
    [MP3-Shield-Panel-v15.brd]
2015-06-26 Updating README, adding license file, cleaning up repo structure
    [MP3-Shield-Panel-v15.brd, SparkFunMP3Shield.brd, SparkFunMP3Shield.sch]
2021-12-15 Correct CS pin to default
    [MP3_PlayTrack.ino]
2024-09-27 Use traces to close jumpers
    [SparkFunMP3Shield.brd, SparkFunMP3Shield.sch]

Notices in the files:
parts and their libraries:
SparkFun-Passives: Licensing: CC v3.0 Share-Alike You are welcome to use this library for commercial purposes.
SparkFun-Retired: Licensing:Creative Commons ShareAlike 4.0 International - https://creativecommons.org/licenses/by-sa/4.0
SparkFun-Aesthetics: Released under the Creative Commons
